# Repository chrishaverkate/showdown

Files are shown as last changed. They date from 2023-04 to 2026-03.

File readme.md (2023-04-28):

# Overview
A modern remake of my senior project from college. 

"Smoke & Hope" was my college project and was a competition shooting timer. It originally used:
* FPGA development board
  * I designed a soft-core processor and a custom DSP module in VHDL
  * Wrote the timing and graphics in C++
* Custom vibration sensor (for detecting the gun shot)
* Resistive touch screen

This project (also named after a classic competition shooting course) is a "re-take". I'm looking to:
* Modernize
* Miniaturize
* Make portable

## Features
* Built on the Raspberry Pi Pico
* 1.14 inch LCD display
* Custom PCB for the vibration sensor circuit
* Battery powered
* 3D printed case

## Resources
* [Raspberry Pi Pico](https://www.raspberrypi.org/products/raspberry-pi-pico/)
* [1.14 inch LCD display](https://www.pishop.us/product/1-14inch-lcd-display-module-for-raspberry-pi-pico-65k-colors-240-135-spi/)
* [Battery](https://www.pishop.us/product/lithium-ion-polymer-battery-3-7v-900mah/)

### Prerequisites
* [Docker](https://docs.docker.com/get-docker/)
* [Pico Probe](https://www.raspberrypi.org/documentation/rp2040/getting-started/#debug-probe)
* [Raspberry Pi Pico](https://www.raspberrypi.org/products/raspberry-pi-pico/)
* [CMake](https://cmake.org/download/)
* Compiler tools for your platform

### Build - Local
To build locally, use the convenience script [run-build-linux.bash](scripts/run-build-linux.bash).
You can see the details of the build for setting up an IDE for more interactive development.
```bash
cd scripts && ./run-build-linux.bash linux
```

### Build - Docker
Again, there is a convenience script [run-build-docker.bash](scripts/run-build-docker.bash).
```bash
cd scripts && ./run-build-docker.bash
```

The benefit to this script is the output will be placed in the 'bin' folder,
and it will be ready to flash to the Pico.

## LCD Display
Using the [Waveshare Pico LCD 1.14](https://www.waveshare.com/wiki/Pico-LCD-1.14) (2 buttons + dpad style).

**Front View**
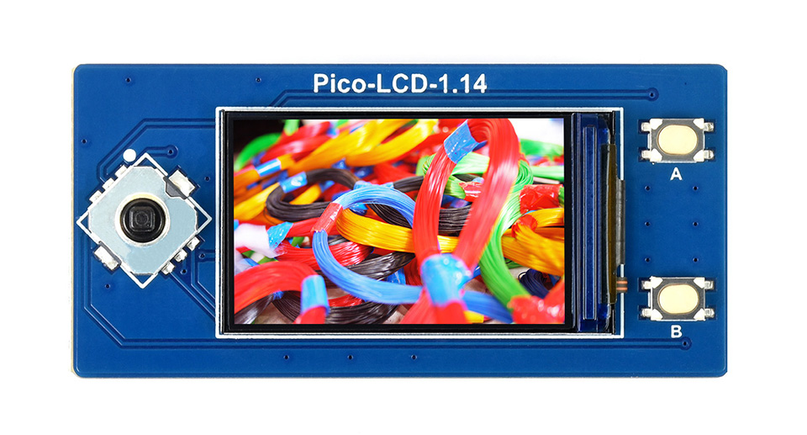
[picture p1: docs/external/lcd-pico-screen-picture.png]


**Pinout**
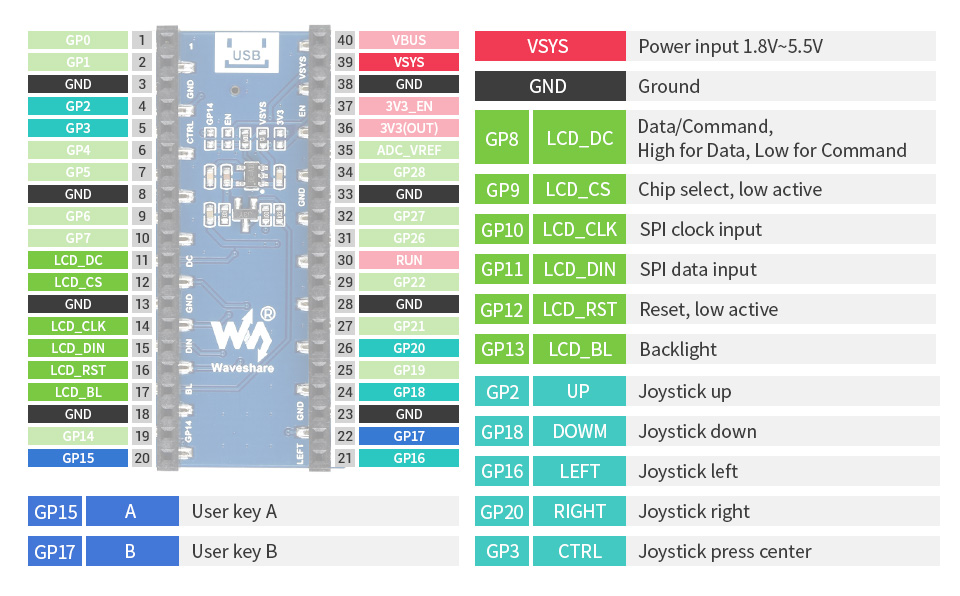
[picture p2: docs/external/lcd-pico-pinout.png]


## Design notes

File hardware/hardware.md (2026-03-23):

 
# Parts
## OpAmp
* [LM2904 OpAmp](docs/external/op-amp%20-%20lm2904b.pdf)
* [LM393 comparator](docs/external/lm393.pdf)

## Piezo Element
Several options to explore:
* [Piezo Vibration Sensor - Large with Mass](https://www.sparkfun.com/piezo-vibration-sensor-large-with-mass.html)
* [Piezo Vibration Sensor - Large](https://www.sparkfun.com/piezo-vibration-sensor-large.html)
* [Piezo Vibration Sensor - Small Vertical](https://www.sparkfun.com/piezo-vibration-sensor-small-vertical.html)
* [Piezo Vibration Sensor - Small Horizontal](https://www.sparkfun.com/piezo-vibration-sensor-small-horizontal.html)
* [Mini Speaker 12mm 2.048kHz](https://www.sparkfun.com/mini-speaker-pc-mount-12mm-2-048khz.html)
* [Piezo Element](https://www.sparkfun.com/piezo-element.html#content-documentation)

# Design

## Digitally Controlled Shot Sensing
All GPIO pins on the Pico can output PWM.
If you run PWM at a high frequency and pass it through a low-pass RC filter, you get a stable analog voltage.

Typical RC filter example:
* R = 10kΩ
* C = 1µF

Gives ~16 Hz cutoff → smooth stable DC output

```python
from machine import Pin, PWM
import time

pwm = PWM(Pin(15))   # any PWM-capable pin
pwm.freq(50000)      # high frequency to help filtering

def set_voltage(v):
    # v is desired voltage 0.0–3.3
    duty = int(v / 3.3 * 65535)
    pwm.duty_u16(duty)

while True:
    set_voltage(1.65)  # output ~1.65V
    time.sleep(1)

```

## Sourcing
* 1x [LM393](https://www.mouser.com/ProductDetail/Texas-Instruments/LM393BIPWR?qs=OlC7AqGiEDk6Hx8FCoL%252BIg%3D%3D)
  * [Datasheet](docs/external/lm393.pdf) 
  * package: TSSOP-8
  * footprint: same
  * price: $0.20 
* 1x [500k Potentiometer](https://www.mouser.com/ProductDetail/Bourns/3386P-DF6-504LF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)
  * [Datasheet](docs/external/pot-500k.pdf)
  * package: through hole
  * footprint: 2-pin header
* price: $2.48
* 2x [Diode 1N4148](https://www.mouser.com/ProductDetail/Panjit/1N4148W_R2_00001?qs=sPbYRqrBIVlsNrvmMQOkFA%3D%3D)
  * [Alt diode 1n4148](https://www.mouser.com/ProductDetail/Diotec-Semiconductor/1N4148W?qs=OlC7AqGiEDmsbkbAeXQtXg%3D%3D)
    * [Datasheet](docs/external/diode%20-%201N4148f.pdf)
  * [Datasheet](docs/external/diode%20-%201N4148.pdf)
  * package: SOD-123-2
  * footprint:
  * price: $0
* 1x [1M Ohm Resistor](https://www.amazon.com/AEDIKO-Capacitor-Resistor-Assortment-Resistors/dp/B096Z6H7SV/ref=sr_1_4?sr=8-4)
  * [Datasheet](docs/external/lm393.pdf)   
  * package: 1206
  * footprint: same
  * price: $6
* 1x 10k Ohm Resistor
  * [Datasheet](docs/external/lm393.pdf)
  * package:
  * footprint:
  * price: $0
* 1x [?uF capacitor](https://www.amazon.com/1206-Capacitor-Kits-16values-Multilayer/dp/B0F5Q8V6BH/ref=sr_1_4?sr=8-4)
  * [Datasheet](docs/external/lm393.pdf)
  * package: 1206
  * footprint: same
  * price: $8

Dev parts
* 1x 1k Ohm Resistor
  * [Datasheet](docs/external/lm393.pdf)
  * package:
  * footprint:
  * price: $0
* 1x green LED
  * [Datasheet](docs/external/lm393.pdf)
  * package:
  * footprint:
  * price: $0

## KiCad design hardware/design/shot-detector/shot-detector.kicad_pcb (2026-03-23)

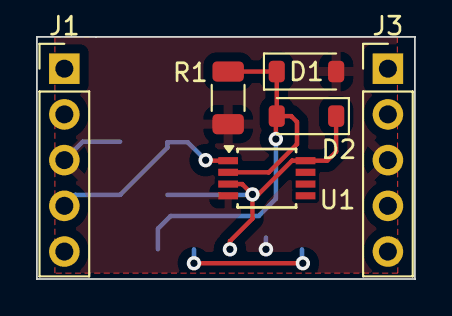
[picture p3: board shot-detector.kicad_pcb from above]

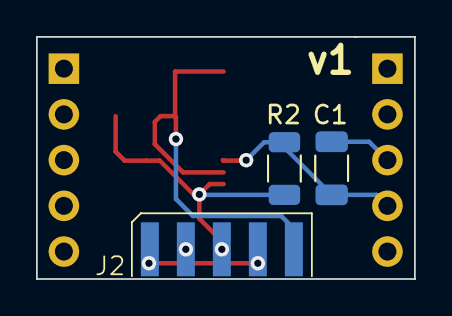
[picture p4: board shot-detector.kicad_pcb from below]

Board: 2 copper layers, 21.0 x 13.5 mm, 9 parts (3 on the bottom side), 5 nets.

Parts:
C1: C; C_1206_3216Metric
D1, D2: 1N4148; D_SOD-123
J1, J3: Conn_01x05; PinHeader_1x05_P2.54mm_Vertical
J2: Conn_01x05; 1x05_smt_wire_solder
R1: 1M; R_1206_3216Metric
R2: 10k; R_1206_3216Metric
U1: LM393; TSSOP-8_3x3mm_P0.65mm

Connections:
+5V: D2.1 (K), J2.3, R2.1, U1.3 (+_in1), U1.8 (V+)
/output: C1.1, J1.4, R2.2, U1.1
/pizo_conditioned: D1.1 (K), D2.2 (A), J2.5, R1.1, U1.2 (-_in1)
/pizo_in: J2.1, J2.4
GND: C1.2, D1.2 (A), J1.3, J2.2, J3.3, R1.2, U1.4 (V-)

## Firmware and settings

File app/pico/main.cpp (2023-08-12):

#pragma clang diagnostic push
#pragma ide diagnostic ignored "EndlessLoop"


#include <memory>
#include <pico/binary_info.h>
#include <pico/stdlib.h>
#include <hardware/pwm.h>
#include <hardware/adc.h>
#include <stdio.h>
#include <vector>


#include "pin_assignments.h"

#include "implementations/lcd_screen.h"
#include "implementations/pico_system.h"

#include <showdown/controller.h>
#include <showdown/event_receiver.h>
#include <showdown/factory.h>
#include <showdown/screen.h>


using std::make_shared;
using std::make_unique;
using std::shared_ptr;
using std::unique_ptr;
using std::vector;

void build_fake_shot_session(unique_ptr<Controller>& controller);

void shot_detection_isr(uint gpio, uint32_t events);
uint32_t pwm_setup(uint8_t pin, uint32_t freq);

void service_buzzer();
void start_buzzer(uint64_t start_time_us);
void stop_buzzer();

template<uint8_t pin>
bool button_pressed();

void onboard_led_heartbeat();
void update_system_info(PicoSystem& system, const unique_ptr<ModelUpdatedReceiver>& model_updated_receiver);
void init_io();

bool g_shot_detected = false;  ///< set by the ISR and serviced + cleared when ack'd
bool g_buzzer_active = false;  ///< set by a callback from the controller and cleared when duration is finished.
uint64_t g_session_started = 0; ///< set by the callback from the controller when a session is started.

#pragma clang diagnostic push
#pragma ide diagnostic ignored "EndlessLoop"
int main(int argc, char** argv) {
	init_io();

	printf("\n\n--------------------------\n- Welcome to Pico\n--------------------------\n");

	printf("Setting up LCD Screen...\n");
	LcdScreen lcd;
	lcd.initialize();

	printf("Setting up PicoSystem Model...\n");
	PicoSystem pico_system;

	printf("Setting up Controller and Views...\n");
	auto controller = Factory::create_controller();
	controller->add_view(ViewType::HOME, static_cast<std::shared_ptr<Screen>>(&lcd));
	controller->add_view(ViewType::TIMELINE, static_cast<std::shared_ptr<Screen>>(&lcd));
	controller->add_view(ViewType::TIME_TABLE, static_cast<std::shared_ptr<Screen>>(&lcd));
	controller->add_view(ViewType::DELTA_TABLE, static_cast<std::shared_ptr<Screen>>(&lcd));
	auto& system_info_view = controller->add_view(ViewType::SYSTEM_INFO, static_cast<std::shared_ptr<System>>(&pico_system), static_cast<std::shared_ptr<Screen>>(&lcd));
	controller->draw_current_view();

	controller->register_new_session_callback(&start_buzzer);

	// Create lambda functions to help wrap the use of a template and reduce the number of functions
	// that are nearly alike.
	auto service_button_a = [&controller]() {
		if (button_pressed<Pins::UI_BTN_A>()) {
			controller->button_pressed_a(get_absolute_time());
		}
	};

	auto service_button_b = [&controller]() {
		if (button_pressed<Pins::UI_BTN_B>()) {
			controller->button_pressed_b(get_absolute_time());
		}
	};

	auto service_button_up = [&controller]() {
		if (button_pressed<Pins::UI_BTN_UP>()) {
			controller->button_pressed_up(get_absolute_time());
		}
	};

	auto service_button_down = [&controller]() {
		if (button_pressed<Pins::UI_BTN_DOWN>()) {
			controller->button_pressed_down(get_absolute_time());
		}
	};

	auto service_button_left = [&controller]() {
		if (button_pressed<Pins::UI_BTN_LEFT>()) {
			controller->button_pressed_left(get_absolute_time());
		}
	};

	auto service_button_right = [&controller]() {
		if (button_pressed<Pins::UI_BTN_RIGHT>()) {
			controller->button_pressed_right(get_absolute_time());
		}
	};


	printf("- Starting Main loop\n");
	while (true) {
		onboard_led_heartbeat();
		update_system_info(pico_system, system_info_view);

		service_button_a();
		service_button_b();
		service_button_up();
		service_button_down();
		service_button_left();
		service_button_right();

		service_buzzer();

		if (g_shot_detected) {
			g_shot_detected = false;
			controller->shot_detected(get_absolute_time());
		}
	}

	return 0;
}
#pragma clang diagnostic pop

void init_io() {
	stdio_init_all();

	// USB Power Sense
	gpio_init(Pins::SENSE_USB_POWER);
	gpio_set_dir(Pins::SENSE_USB_POWER, GPIO_IN);

	adc_init();
	adc_gpio_init(Pins::SENSE_VOLTAGE_VSYS);
	adc_select_input(3);

	// On-baord LED for heartbeat
	gpio_init(Pins::OB_LED);
	gpio_set_dir(Pins::OB_LED, GPIO_OUT);

	// User Buttons
	gpio_init(Pins::UI_BTN_UP);
	gpio_set_dir(Pins::UI_BTN_UP, GPIO_IN);
	gpio_pull_up(Pins::UI_BTN_UP);

	gpio_init(Pins::UI_BTN_DOWN);
	gpio_set_dir(Pins::UI_BTN_DOWN, GPIO_IN);
	gpio_pull_up(Pins::UI_BTN_DOWN);

	gpio_init(Pins::UI_BTN_LEFT);
	gpio_set_dir(Pins::UI_BTN_LEFT, GPIO_IN);
	gpio_pull_up(Pins::UI_BTN_LEFT);

	gpio_init(Pins::UI_BTN_RIGHT);
	gpio_set_dir(Pins::UI_BTN_RIGHT, GPIO_IN);
	gpio_pull_up(Pins::UI_BTN_RIGHT);

	gpio_init(Pins::UI_BTN_A);
	gpio_set_dir(Pins::UI_BTN_A, GPIO_IN);
	gpio_pull_up(Pins::UI_BTN_A);

	gpio_init(Pins::UI_BTN_B);
	gpio_set_dir(Pins::UI_BTN_B, GPIO_IN);
	gpio_pull_up(Pins::UI_BTN_B);

	// Buzzer
	pwm_setup(Pins::BUZZER, 1500);

	// Shot detection interrupt
	gpio_init(Pins::SHOT_DETECTION);
	gpio_pull_up(Pins::SHOT_DETECTION);
	gpio_set_irq_enabled_with_callback(Pins::SHOT_DETECTION, GPIO_IRQ_EDGE_FALL, true, &shot_detection_isr);

	printf("\n\n -> IO Initialized!\n");
}

/** @brief Setup the an IO pin as a PWM output
 * @param pin [in] The GPIO pin to configure for PWM
 * @param freq [in] The frequency in Hz
 * @param d [in] The duty cycle in percent
 * @return
 */
uint32_t pwm_setup(uint8_t pin, uint32_t freq) {
	gpio_set_function(pin, GPIO_FUNC_PWM);
	uint8_t slice_num = pwm_gpio_to_slice_num(pin);
	uint8_t chan = pwm_gpio_to_channel(pin);

	uint8_t duty_cycle = 50;
	uint32_t clock = 125000000;
	uint32_t divider16 = clock / freq / 4096 + (clock % (freq * 4096) != 0);
	if (divider16 / 16 == 0)
		divider16 = 16;

	uint32_t wrap = clock * 16 / divider16 / freq - 1;
	pwm_set_clkdiv_int_frac(slice_num, divider16 / 16, divider16 & 0xF);
	pwm_set_wrap(slice_num, wrap);
	pwm_set_chan_level(slice_num, chan, wrap * duty_cycle / 100);
	return wrap;
}

void shot_detection_isr(uint gpio, uint32_t events) {
	printf("Shot detected!\n");
//	static const int debounce_delay = 50;

	if (gpio == Pins::SHOT_DETECTION) {
		if (gpio_get(Pins::SHOT_DETECTION) == 0) {
			g_shot_detected = true;
		}
	}
}

template<uint8_t pin>
bool button_pressed() {
	static int last_button_state = 0;
	const int button_state = gpio_get(pin);

	if (button_state != last_button_state) {
		if (button_state == 0) {
			printf("Button %d pressed\n", pin);
			return true;
		}
		last_button_state = button_state;
	}

	return false;
}

void service_buzzer() {
	static const uint64_t DURATION = 100 * 100 * 2;

	if(g_buzzer_active) {
		const uint64_t now = get_absolute_time();
		const bool buzzer_finished = (now - g_session_started) > DURATION;

		if (buzzer_finished) {
			stop_buzzer();
		}
	}
}

void start_buzzer(uint64_t start_time_us) {
    uint slice_num = pwm_gpio_to_slice_num(Pins::BUZZER);
	pwm_set_enabled(slice_num, true);
	g_buzzer_active = true;
	g_session_started = start_time_us;
}

void stop_buzzer() {
	uint slice_num = pwm_gpio_to_slice_num(Pins::BUZZER);
	pwm_set_enabled(slice_num, false);
	g_buzzer_active = false;
}

void onboard_led_heartbeat() {
	static const uint64_t HB_PERIOD = 500000;  // us
	static uint64_t last_time = 0;
	static bool state = false;

	const uint64_t now = get_absolute_time();

	if ((now - last_time) > HB_PERIOD) {
		state = !state;
		last_time = now;
		gpio_put(Pins::OB_LED, state);
	}
}

void update_system_info(PicoSystem& system, const unique_ptr<ModelUpdatedReceiver>& model_updated_receiver) {
	static const uint64_t HB_PERIOD = 5000000;  // us
	static uint64_t last_time = 0;

	const uint64_t now = get_absolute_time();

	if ((now - last_time) > HB_PERIOD) {
		system.update();
		model_updated_receiver->model_updated();
	}
}

#pragma clang diagnostic pop

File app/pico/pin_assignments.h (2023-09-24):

#pragma once

#include <cstdio>
#include <stdint.h>

/** @brief The pin designations are in GPIO numbers. Refer to the Pico Pinout diagram.
 */
namespace Pins {
/*******************************************************************************
 * Sensors
 ******************************************************************************/
static const uint8_t SENSE_USB_POWER = 24;     // Identifies if USB power is present
static const uint8_t SENSE_VOLTAGE_VSYS = 29;  // Voltage of the system


/*******************************************************************************
 * Visual / Audio
 ******************************************************************************/

static const uint8_t OB_LED = 25;    // On-board LED - show pico has life

/* Pin 21 was carefully selected because it uses PWM Generator slice 2 channel B (1),
 * which is shared with pin 5. Pin 5 should be avoided.
 */
static const uint8_t BUZZER = 21;    // Buzzer
static const uint8_t DEAD_PIN = 5;   // Do not use this pin

// Shot detection
static const uint8_t SHOT_DETECTION = 14;

/*******************************************************************************
 * Communications
 ******************************************************************************/

// Debug communication
static const uint8_t UART_TX = 0;
static const uint8_t UART_RX = 1;

// SPI Lines
//static const uint8_t SPI_0_MOSI = 16;
//static const uint8_t SPI_0_CS = 17;//static const uint8_t SPI_0_SCK = 18;
//static const uint8_t SPI_0_MISO = 19;

// i2c port 0
//static const uint8_t I2C_0_SDA = 20;
//static const uint8_t I2C_0_SCL = 21;

// i2c port 1
//static const uint8_t I2C_1_SDA = 26;
//static const uint8_t I2C_1_SCL = 27;

/*******************************************************************************
 * Reserved for LCD
 ******************************************************************************/
// Buttons
static const uint8_t UI_BTN_A = 15;
static const uint8_t UI_BTN_B = 17;

static const uint8_t UI_BTN_LEFT = 2;   // documented as up
static const uint8_t UI_BTN_RIGHT = 18; // documented as down
static const uint8_t UI_BTN_DOWN = 16;  //documented as left
static const uint8_t UI_BTN_UP = 20;    // documented as right
static const uint8_t UI_BTN_CENTER = 3;

/* Declared in the LCD library
EPD_RST_PIN  = 12;
EPD_DC_PIN   = 8;
EPD_BL_PIN   = 13;

EPD_CS_PIN   = 9;
EPD_CLK_PIN  = 10;
EPD_MOSI_PIN = 11;

EPD_SCL_PIN  = 7;
EPD_SDA_PIN  = 6;
*/
}  // namespace Pins

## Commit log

2023-04-28 Initial setup of the project.
    It builds and runs some UI from my pico-eye project, but is enough to prove the wiring on my dev board.
2023-04-29 Tinkering with screen settings.
    Mostly just getting the screen working and testing button input.
2023-04-30 Proof of Concept for one screen with scrolling.
    I tried drawing out a potential (novel) visualization of a shot timeline. The screen includes scrolling, so that many shots could be displayed.
    Also includes initial attempts at setting up a buzzer (not working yet).
    [main.cpp, pin_assignments.h]
2023-04-30 Basic buzzer operation.
    Just proving out a possible buzzer configuration.
    [main.cpp, pin_assignments.h]
2023-05-07 Controller tests are started.
    This prompted some designing of the class structure and starting to fill in some of the skeleton of the project.
    Internal mechanics of Controller can track a list of views and switch the active view based on button presses.
2023-05-09 Views and switching views works!!
    There is a lot here, but the gist is that a pico specific screen that meets the showdown interface can be created and passed into a number of views on the showdown controller.
    Very basic button presses are captured and sent to the controller, which will change which view is being drawn.
2023-05-11 Getting the Session class connected to the Timeline view.
    Includes some hardcoded data in main for consistent testing while getting the session model correctly working. The Timeline view is also getting a first pass implementation. It's starting to come alive!
    [main.cpp]
2023-05-13 Getting test build to work on Mac.
    Mostly just moving uint to uint8_t and adding a couple cmake files.
2023-05-31 Optimizing drawing so old shots are not re-drawn.
    Drawing on the 3 data screens is a lot faster for each consecutive shot. Also, connected the 'A' button to shot_detected for now.
2023-06-18 Setting up shot detection interrupt.
2023-07-04 Buzzer now works properly.
    The buzzer starts when a new session is started and lasts for a configured time. Shots can be detected even while the buzzer is still sounding.
    Also, includes some refactoring to the button functions. Combining lambdas and templates to share as much code as possible.
    [main.cpp]
2023-07-05 Starting the hardware design for shot detector circuit
    [shot-detector.kicad_pcb, shot-detector.kicad_sch]
2023-07-29 Starting to design hardware stack-up and introducing system info view.
    The goal of system info is to display battery information.
2023-08-12 Introducing System Info screen.
    The system will now determine if it is running on battery power or plugged in charging. The full system is operational either way, and the details of the battery is displayed on a system info screen.
    There is still work needed to get the screen to know when to update based on changes to system info.
2023-08-12 Added a way for a view to get a callback when the model is updated, skipping the controller.
    The good: now the system info is updated any time the system changes state and can directly invoke the correct view. This keeps the controller from needing to know anything special about the views it holds and where they are in the list.
    The bad: seems a little complicated... also, the views now need to know if they are "active". Similar to an app or window knowing it's in the foreground or open.
    [main.cpp]
2023-09-24 Working on the physical stackup.
    Updating diagram to show connection between Pico and other devices. Moving shot detection pin to be accessible by shot detection PCB.
2023-09-24 Adding Pico Lipo Shim documentation.
2025-12-22 Updating schematic to use the LM393 along with some related docs
    [shot-detector.kicad_sch]
2026-03-15 Progress on schematic and PCB.
    Finished getting all the parts placed, and most all footprints.
    Getting the general layout started on PCB.
    [shot-detector.kicad_pcb, shot-detector.kicad_sch]
2026-03-16 First pass of PCB layout.
    [shot-detector.kicad_pcb, shot-detector.kicad_sch]
2026-03-23 V1 of PCB ordered.
    [shot-detector-B_Cu.gbr, shot-detector-B_Mask.gbr, shot-detector-B_Paste.gbr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]
